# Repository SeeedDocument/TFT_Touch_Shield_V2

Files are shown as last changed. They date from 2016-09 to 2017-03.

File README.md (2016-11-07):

# 2.8TFT Touch Shield
---
SKU: 104030004

Wiki Link: [wiki.seeed.cc](wiki.seeed.cc)

Change Log:

- 2016-11-7: create repos by Jeremy (Jeremy.xiao@seeed.cc)

## About Seeed

Seeed is a hardware innovation platform for makers to grow inspirations into differentiating products. By working closely with technology providers of all scale, Seeed provides accessible technologies with quality, speed and supply chain knowledge. When prototypes are ready to iterate, Seeed helps productize 1 to 1,000 pcs using in-house engineering, supply chain management and agile manufacture forces. Seeed also team up with incubators, Chinese tech ecosystem, investors and distribution channels to portal Maker startups beyond.

## Contribution

We warmly welcome contribution to this documentation project. You can do this basically by [forking](https://help.github.com/articles/fork-a-repo), committing modifications and then [pulling requests](https://help.github.com/articles/using-pull-requests) (follow the links above for operating guide). Adding change log and your contact into file header is encouraged. Thanks for your contribution.

LICENSE
-------
Copyright (c) 2008-2016 Seeed Development Limited (www.seeedstudio.com / www.seeed.cc)

### Documents and Images
</a><br />
This work (product documents and associated images) are licensed under a <a rel="license" href="http://creativecommons.org/licenses/by-sa/4.0/">Creative Commons Attribution-ShareAlike 4.0 International License</a>. 

### Software Library
All demo software, code examples embedded in the document and any software libraray provided with the product document are licensed under [MIT License](https://github.com/SeeedDoc/WikiMigrationSync/blob/master/MIT_LICENSE "MIT LICENSE") unless otherwise specified.

### Thirdparty content
The resources provided with the product documents also contains datasheets, software examples and other content copyrighted by 3rd party authors and companies. All such items are copyright of respective owners. The use of such items are governed by their respective licenses.

All trademarks are the property of their respective owners.

### To Contact

Write to us at  with subject line "Wiki". Thanks

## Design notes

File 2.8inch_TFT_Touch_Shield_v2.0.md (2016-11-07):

---
title: 2.8'' TFT Touch Shield v2.0
category: Arduino
bzurl: https://www.seeedstudio.com/2.8-TFT-Touch-Shield-V2.0-p-1286.html
oldwikiname: 2.8''_TFT_Touch_Shield_v2.0
prodimagename: main.jpg
surveyurl: https://www.research.net/r/tft_touch_shield_v2
sku: 104030004
---

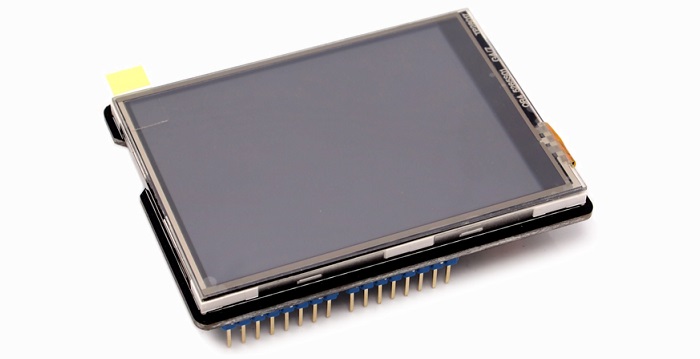
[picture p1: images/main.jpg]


This is a multifunctional Arduino/Seeeduino/Arduino Mega compatible resistive touch screen. It can be used as display device or sketch pad.Compared with the previous version, 2.8``TFT Touch Shield V1.0, we replaced the screen driver with a more professional chip, ILI9341 driver, providing different pin-saving SPI communication without sacrificing the data transmitting speed. Due to the communication method change, programs developed for the original version need modifications before being transplanted to the new version. With a SD card module integrated also on this shield, this shield reserves great room for other expansions to your project.

(http://www.seeedstudio.com/2.8-TFT-Touch-Shield-V2.0-p-1286.html)  

## Features

* Big screen for easy and comfortable experience
* Backlight controllable via programming
* 65k rich colors display
* SPI pin-saving communication method
* Full screen touch active range

## Specification

| Item | Value |
|---|---|
|Working Voltage | 5 V |
|Resolution | 320 x 240 |
| Colors | 65k |

## Application Ideas

* Game
* Sensor Hub
* Human Machine Interface
* Smart House

Here are some awesome projects for your reference. If you have project want to add to this chapter, please feel free to contact loovee@seeed.cc.

|Arduino Phone|Facebook Monitor|Instrucatbles Monitor|
|---|---|---|
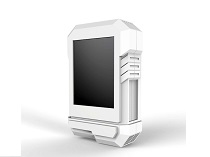
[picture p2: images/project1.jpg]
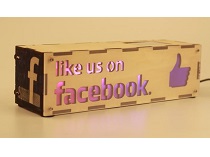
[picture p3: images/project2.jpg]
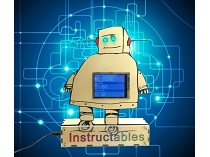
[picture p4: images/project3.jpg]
||||
|[Make it Now!](http://www.instructables.com/id/ArduinoPhone-20-an-Open-Source-Mobile-Phone-Based-/)|[Make it Now!](http://www.instructables.com/id/Facebook-Like-Monitor/)|[Make it Now!](http://www.instructables.com/id/Make-a-Instructables-Indicator/)|

## Pin Used

!!!Note
    You can use the NOT USED pins to control the others module.

Digital Pins

| Pin Name | Function |
|---|---|
|D0 | NOT USED
|D1 | NOT USED |
|D2 | NOT USED |
|D3 | NOT USED |
|D4 | **TF_CS** |
|D5 | **TFT_CS** |
|D6 | **TFT_DC** |
|D7 | **BACKLIGHT(Selectable)**|
|D8 | NOT USED |
|D9 | NOT USED |
|D10 | NOT USED |
|D11 | **SPI_MOSI** |
|D12 | **SPI_MISO** |
|D13 | **SPI_SCK** |

Analog Pins

| Pin Name | Function |
| ---|---|
|A0 | **TOUCH PANEL**		 |
|A1 | **TOUCH PANEL** |
|A2 | **TOUCH PANEL** |
|A3 | **TOUCH PANEL** |
|A4 | NOT USED |
|A5 | NOT USED |

## Getting Started

!!!Note
    This getting started is based on Win10 and Arduino IDE 1.6.9

Here we will show you how this display work, we need thing as below to start.

| Seeeduino V4 | 2.8 TFT Touch Shield V2 | Micro USB Cable |
|---|---|---|
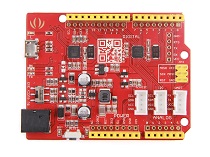
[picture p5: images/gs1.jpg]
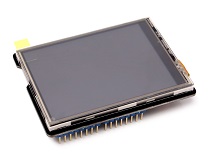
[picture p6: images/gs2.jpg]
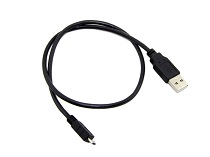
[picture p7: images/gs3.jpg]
||||
| [More Details](http://www.seeedstudio.com/Seeeduino-V4.2-p-2517.html) | [More Details](http://www.seeedstudio.com/2.8-TFT-Touch-Shield-V2.0-p-1286.html) | [More Details](http://www.seeedstudio.com/Micro-USB-Cable-48cm-p-1475.html) |

###Download Arduino Library

This library work for:

* Arduino/Genuino UNO
* Seeeduino V3/4.0/4.2
* Arduino/Genuino Mega
* Arduino Leonardo
* Seeeduino Lite/Clio/Lotus
* LinkIt ONE(Touch panel don't work)

Click on the below button to download the library and install it [(HOW TO INSTALL AN ARDUINO LIBRARY)](http://wiki.seeed.cc/Tutorial/How_to_Install_an_Arduino_Library/).

(https://github.com/Seeed-Studio/TFT_Touch_Shield_V2/archive/master.zip)

This library include few examples,

* drawCircle
* drawLines
* drawNumber
* drawRectangle
* paint
* shapes
* text
* tftbmp
* tftbmp2

We use shapes example for this demo.

###Connection and Upload the code

Insert the board to Seeeduino, and open your Arduino IDE. Click on **File > Examples > TFT_Touch_Shield_V2-master > shapes** to open the code.

Select the correct COM port and Boards(Seeeduino V4), upload the code to Seeeduino, then it's done. If you have any question about how to start the uploading, please put had on [here](http://wiki.seeed.cc/Platform/Arduino/SeeeduinoV4.2/#getting-started) to get more details.

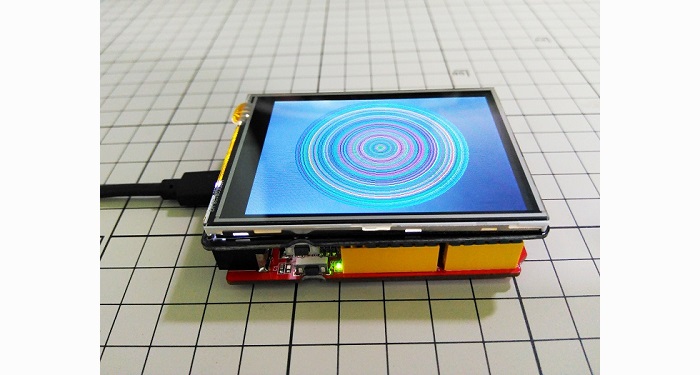
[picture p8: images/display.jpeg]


## Backlight

The backlight is default on always, if you want to control the backlight, you need to do some hack in the board. Please look at the back side of the board, there's a BACKLIGHT label, and one side named ON the other side named D7. We need to cut the wire at ON side and solder D7 side. As shown below.

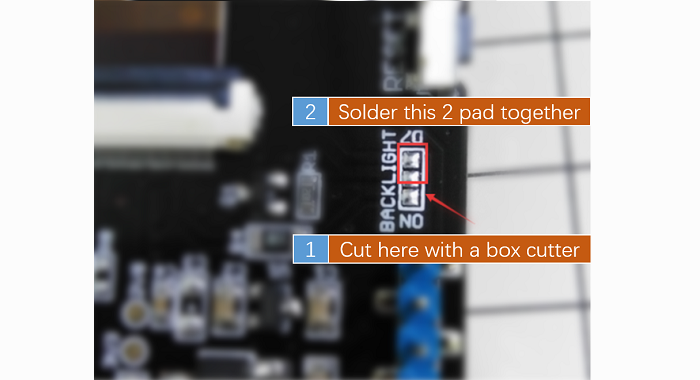
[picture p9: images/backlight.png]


Then you can control the backlight via control D7.

 To open backlight:
     digitalWrite(7, HIGH);

To close backlight:
    digitaWrite(7, LOW);

!!!Warning
    Please be careful when use a box cutter and soldering iron.

## Resources

* [Schematic in Eagle File](https://github.com/SeeedDocument/TFT_Touch_Shield_V2/raw/master/resources/TFT_Eagle_File.zip)
* [TFT Touch Shield Schematic.PDF](https://github.com/SeeedDocument/TFT_Touch_Shield_V2/raw/master/resources/TFT%20Touch.pdf)
* [Library at Github page](https://github.com/Seeed-Studio/TFT_Touch_Shield_V2)
* [Github page of this document](https://github.com/SeeedDocument/TFT_Touch_Shield_V2)

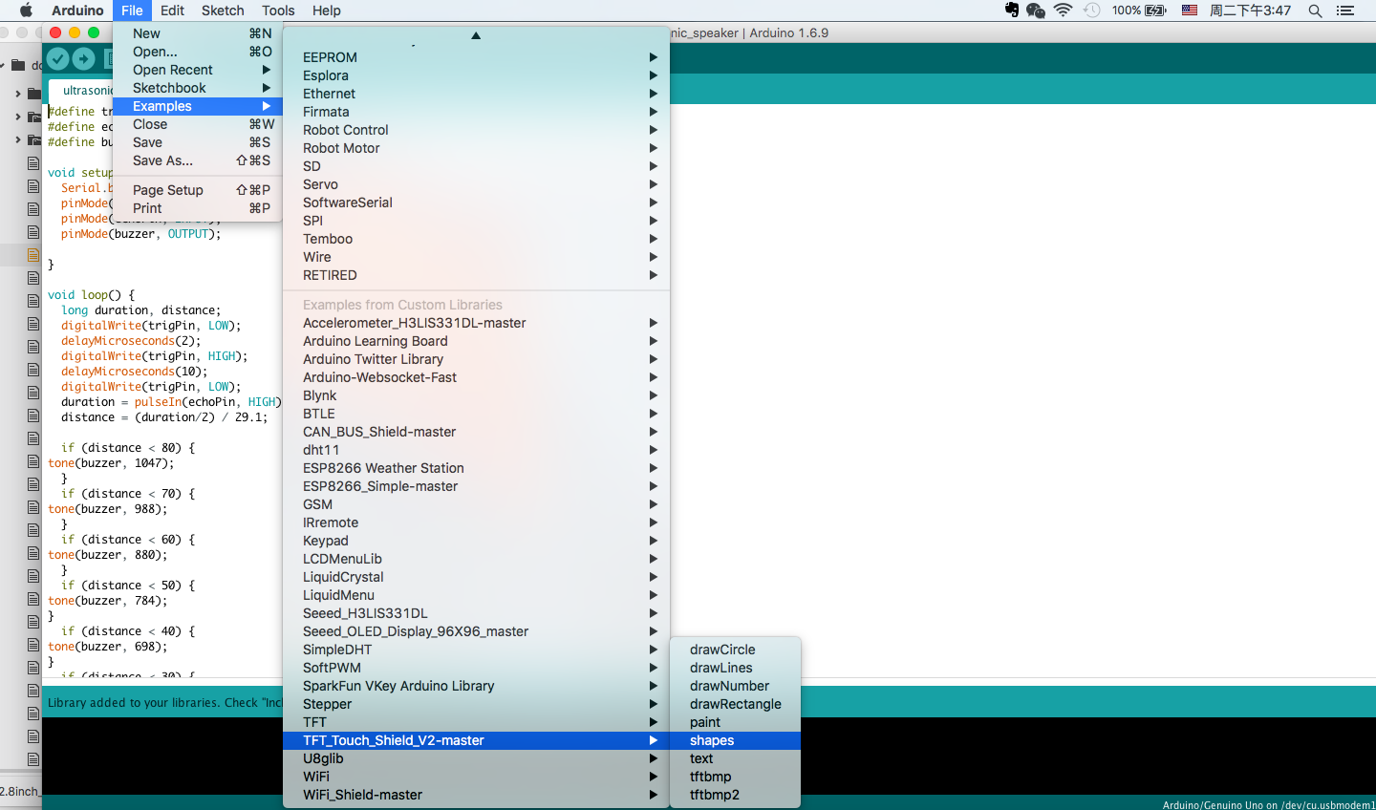
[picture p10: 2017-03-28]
images/shapes example.png

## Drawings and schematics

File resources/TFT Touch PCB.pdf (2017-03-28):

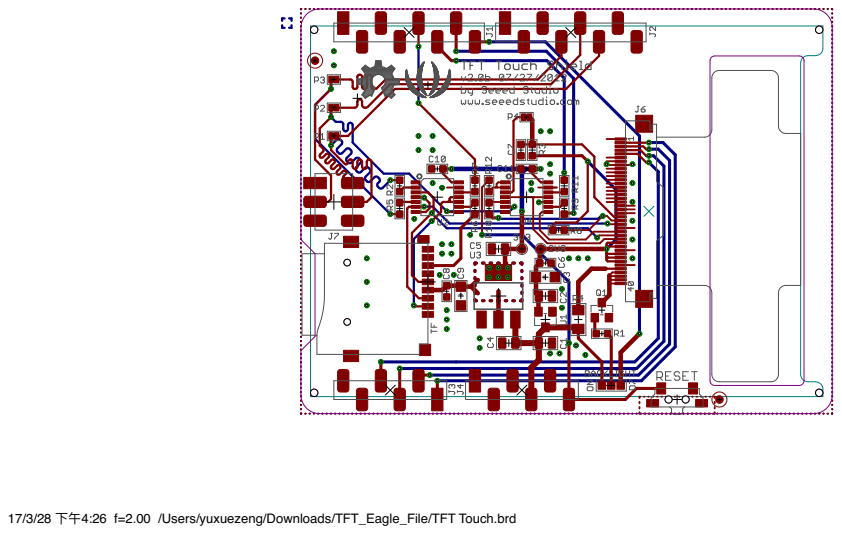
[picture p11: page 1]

17/3/28 下午4:26 f=2.00 /Users/yuxuezeng/Downloads/TFT_Eagle_File/TFT Touch.brd

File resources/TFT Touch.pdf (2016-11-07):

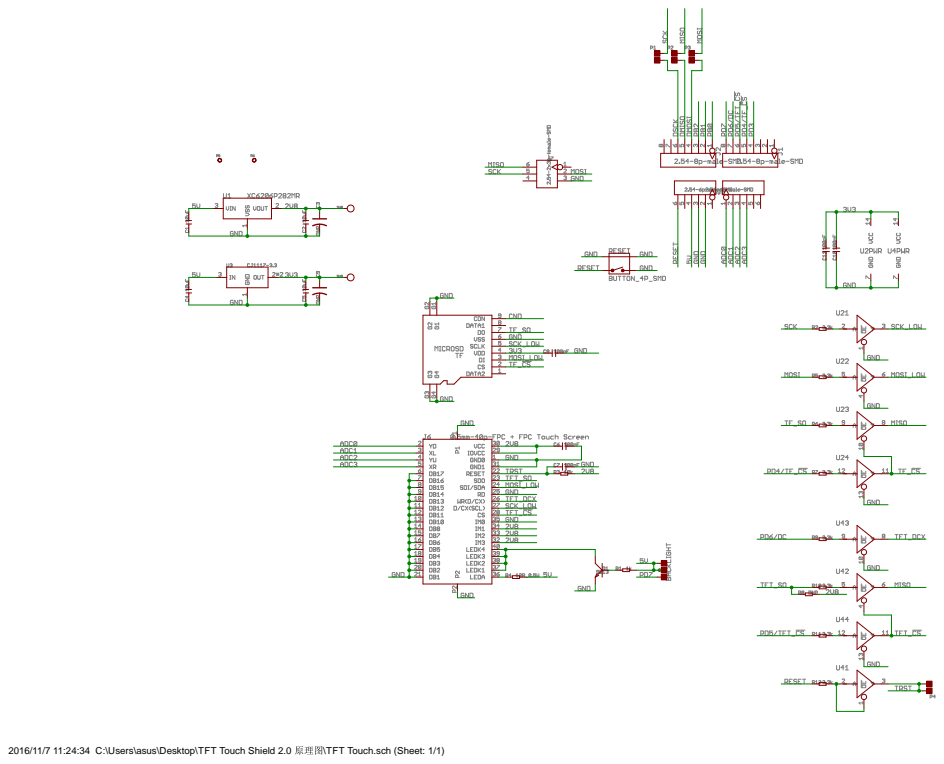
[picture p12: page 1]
2016/11/7 11:24:34 C:\Users\asus\Desktop\TFT Touch Shield 2.0; \TFT Touch.sch (Sheet: 1/1)

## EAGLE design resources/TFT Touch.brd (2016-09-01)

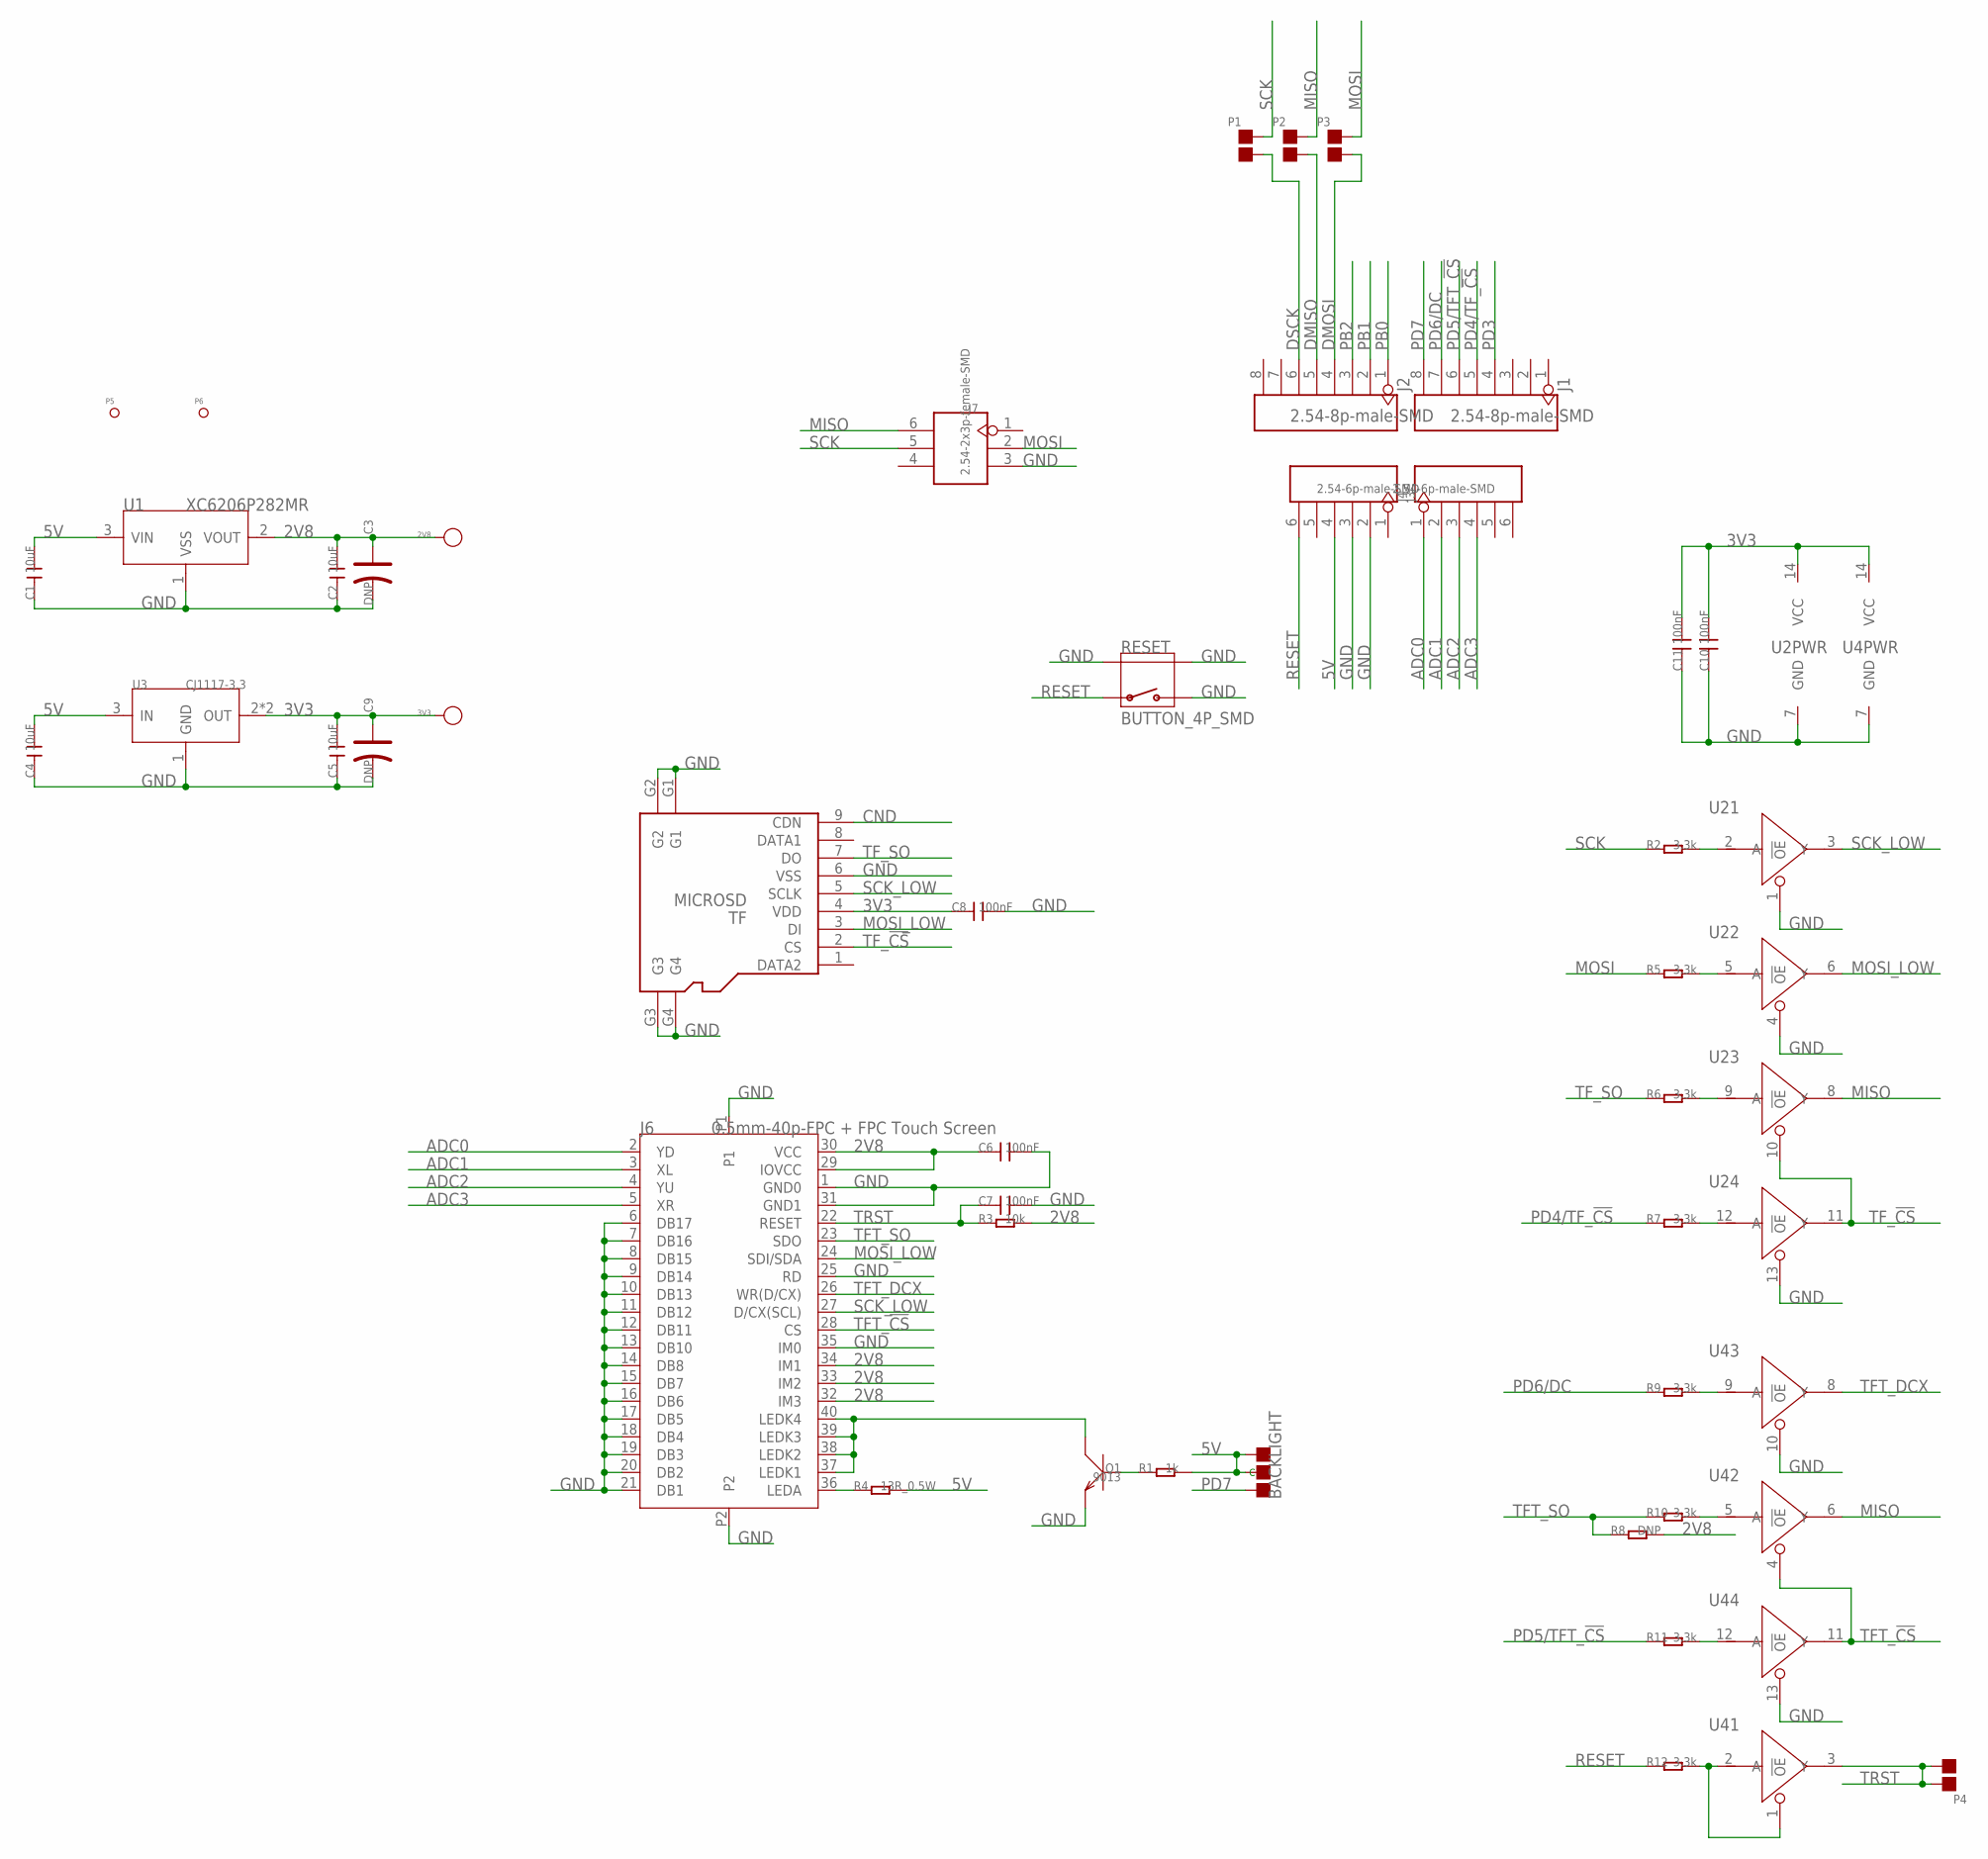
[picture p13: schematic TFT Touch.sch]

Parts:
2V8, 3V3: PAD-TEST-POINT-CIRCLE'4545'; TP_4545
BACKLIGHT: DNP; 3P-SMD-4.1X1.5
C1, C2, C4, C5: 10uF; C0805
C3, C9: DNP; AVX-A
C6, C7, C8, C10, C11: 100nF; 0603@1
J1, J2: 2.54-8p-male-SMD; 8P-2.54-SMD
J3, J4: 2.54-6p-male-SMD; 6P-2.54-SMD
J6: 0.5mm-40p-FPC + FPC Touch Screen; 2.8TFT_FFC
J7: 2.54-2x3p-female-SMD; 2X3P-2.54-SMD
P1, P2, P3, P4: PAD-JUMPER-2P; 2P-SMD-1.78X1.27
P5, P6: PAD-MARK; ROUND-MARK-1.0
Q1: 9013; SOT23
R1: 1k; R0603
R2, R5, R6, R7, R9, R10, R11, R12: 3.3k; R0603
R3: 10k; R0603
R4: 13R_0.5W; R1206
R8: DNP; R0603
RESET: BUTTON_4P_SMD; 4P-SMD-7X3.5X3.5
TF: MICROSD
U1: XC6206P282MR; SOT23
U2, U4: 74VHC125PW; TSSOP14
U3: CJ1117-3.3; SOT-223

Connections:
2V8: 2V8.T, C2.2, C3.+, C6.1, J6.29 (IOVCC), J6.30 (VCC), J6.32 (IM3), J6.33 (IM2), J6.34 (IM1), R3.2, R8.2, U1.2 (VOUT)
3V3: 3V3.T, C5.2, C8.1, C9.+, C10.2, C11.2, TF.4 (VDD), U2.14 (VCC), U3.2 (OUT), U3.TER (OUT), U4.14 (VCC)
5V: BACKLIGHT.00 (L), BACKLIGHT.MM (C), C1.2, C4.2, J4.4, R1.2, R4.2, U1.3 (VIN), U3.3 (IN)
ADC0: J3.1, J6.2 (YD)
ADC1: J3.2, J6.3 (XL)
ADC2: J3.3, J6.4 (YU)
ADC3: J3.4, J6.5 (XR)
CND: TF.9 (CDN)
DMISO: J2.5, P2.1
DMOSI: J2.4, P3.1
DSCK: J2.6, P1.1
GND: C1.1, C2.1, C3.-, C4.1, C5.1, C6.2, C7.2, C8.2, C9.-, C10.1, C11.1, J4.2, J4.3, J6.1 (GND0), J6.6 (DB17), J6.7 (DB16), J6.8 (DB15), J6.9 (DB14), J6.10 (DB13), J6.11 (DB12), J6.12 (DB11), J6.13 (DB10), J6.14 (DB8), J6.15 (DB7), J6.16 (DB6), J6.17 (DB5), J6.18 (DB4), J6.19 (DB3), J6.20 (DB2), J6.21 (DB1), J6.25 (RD), J6.31 (GND1), J6.35 (IM0), J6.P1, J6.P2, J7.3, Q1.2 (E), RESET.2, RESET.S1, RESET.S2, TF.6 (VSS), TF.G1, TF.G2, TF.G3, TF.G4, U1.1 (VSS), U2.1 (!OE), U2.4 (!OE), U2.7 (GND), U2.13 (!OE), U3.1 (GND), U4.7 (GND), U4.10 (!OE), U4.13 (!OE)
MISO: J7.6, P2.2, U2.8 (Y), U4.6 (Y)
MOSI: J7.2, P3.2, R5.1
MOSI_LOW: J6.24 (SDI/SDA), TF.3 (DI), U2.6 (Y)
unnamed: R2.2, U2.2 (A)
unnamed: Q1.1 (B), R1.1
unnamed: J6.37 (LEDK1), J6.38 (LEDK2), J6.39 (LEDK3), J6.40 (LEDK4), Q1.3 (C)
unnamed: R5.2, U2.5 (A)
unnamed: R6.2, U2.9 (A)
unnamed: R11.2, U4.12 (A)
unnamed: R10.2, U4.5 (A)
unnamed: J6.36 (LEDA), R4.1
unnamed: R9.2, U4.9 (A)
unnamed: R7.2, U2.12 (A)
PB0: J2.1
PB1: J2.2
PB2: J2.3
PD3: J1.4
PD4/TF_!CS: J1.5, R7.1
PD5/TFT_!CS: J1.6, R11.1
PD6/DC: J1.7, R9.1
PD7: BACKLIGHT.11 (R), J1.8
RESET: J4.6, R12.1, RESET.1
SCK: J7.5, P1.2, R2.1
SCK_LOW: J6.27 (D/CX(SCL)), TF.5 (SCLK), U2.3 (Y)
TFT_!CS: J6.28 (CS), U4.4 (!OE), U4.11 (Y)
TFT_BUF: R12.2, U4.1 (!OE), U4.2 (A)
TFT_DCX: J6.26 (WR(D/CX)), U4.8 (Y)
TFT_SO: J6.23 (SDO), R8.1, R10.1
TF_!CS: TF.2 (CS), U2.10 (!OE), U2.11 (Y)
TF_SO: R6.1, TF.7 (DO)
TRST: C7.1, J6.22 (RESET), P4.1, P4.2, R3.1, U4.3 (Y)

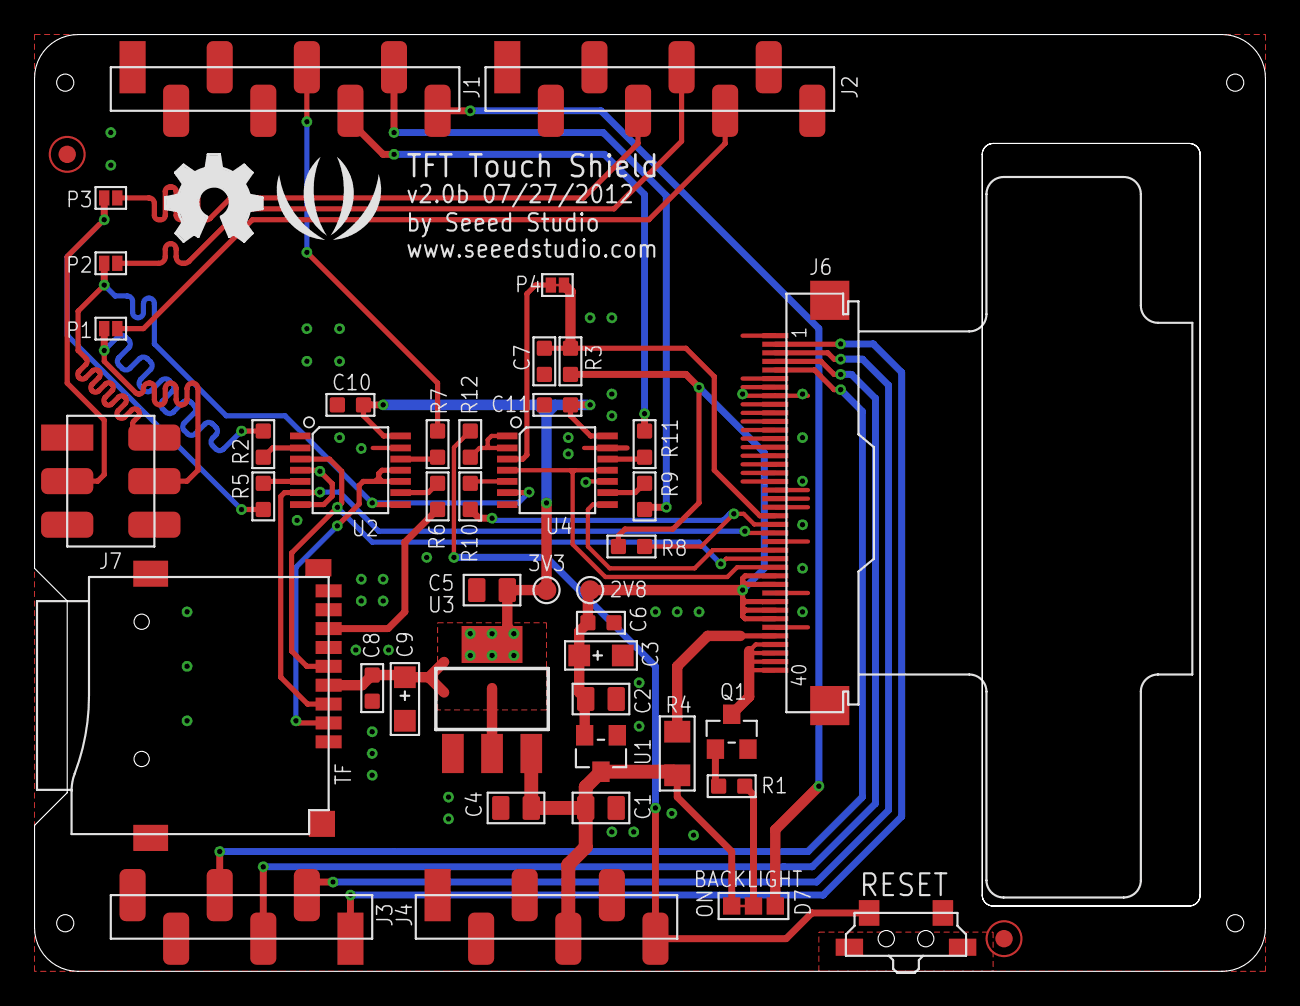
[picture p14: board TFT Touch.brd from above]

Board: 2 copper layers, 71.8 x 54.6 mm, 47 parts (1 on the bottom side), 38 nets.

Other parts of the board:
U$1: OSHW_FILLX200_NOTEXT
U$2: LOGO_SILK

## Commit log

2016-09-01 add images and resources
    [TFT Touch.brd, TFT Touch.sch]
2016-09-01 add library button image
2017-03-28 add PCB pdf file

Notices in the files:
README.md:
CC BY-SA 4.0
